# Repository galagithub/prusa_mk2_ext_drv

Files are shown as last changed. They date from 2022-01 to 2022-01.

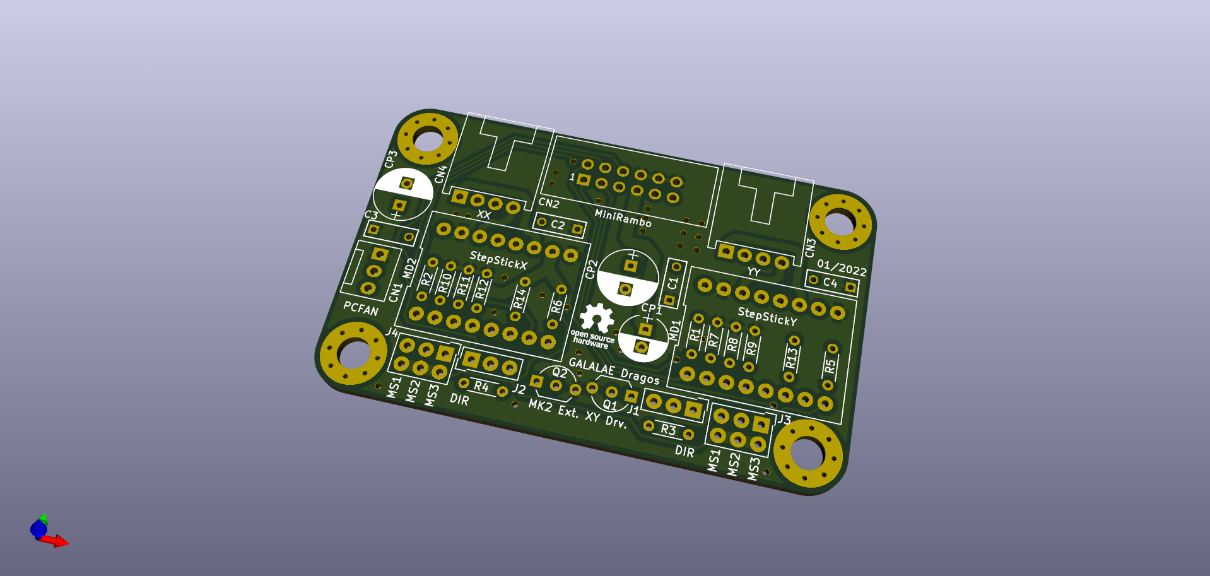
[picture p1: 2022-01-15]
docs/prusa_mk2_ext_drv_v01_2022.png

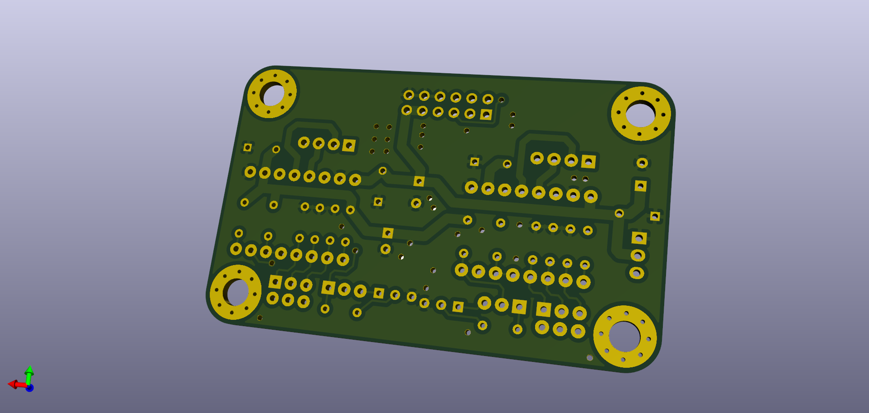
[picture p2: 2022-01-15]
docs/prusa_mk2_ext_drv_v01_2022_back.png

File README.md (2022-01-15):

This is a PCB made to replace the X and Y drivers used the Prusa MK2(S) or MK2.5(S) series of 3D printers.

A closed source kit can be purchased on the web, but the cost is prohibitive for large quantities.
So I have scoured the web for info about the controller used in the 3D printer, MiniRambo v1.3.
Eventually, I managed to compile the schematics enclosed in this github project.

I have used KiCAD v5.1 to design a PCB similar in dimensions to the closed source kit.
Reason being the availability of ready made 3D enclosure(s), the recommended one can be found here:
https://www.thingiverse.com/thing:2777899

Dimensions for the PCB were "recovered" using MeshLab on the above 3D enclosure(s).

Resources:
1) https://reprap.org/wiki/MiniRambo
2) https://reprap.org/wiki/RAMPS_1.4
3) https://reprap.org/wiki/StepStick
4) https://learn.watterott.com/silentstepstick/pinconfig/tmc2209/
5) https://www.thingiverse.com/thing:2777899
6) https://vmod.wordpress.com/prusa-mk2s-ext-driver-board-v2-3/
7) https://www.kicad.org/

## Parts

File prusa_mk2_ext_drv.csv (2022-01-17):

Id | Designator | Package | Quantity | Designation | Supplier and ref
1 | CN4 | Molex_70553_4P | 1 | Y_MOT
2 | CP1 | CP_Radial_D6.3mm_P2.50mm | 1 | 47u/35V
3 | J1 | JP_2.54mm_3PIN | 1 | DirRevX
4 | MD1 | STEPSTICK | 1 | TMC2209_X
5 | MD2 | STEPSTICK | 1 | TMC2209_Y
6 | Q1,Q2 | TO-92_Inline_Wide | 2 | BC546
7 | R2,R6,R1,R5,R13,R14 | R_Axial_DIN0204_L3.6mm_D1.6mm_P5.08mm_Horizontal | 6 | 10k
8 | R4,R11,R3,R10,R12,R8,R7,R9 | R_Axial_DIN0204_L3.6mm_D1.6mm_P5.08mm_Horizontal | 8 | 100k
9 | REF**,REF**,REF**,REF** | MountingHole_4.3mm_M4_Pad_Via | 4 | MountingHole_4.3mm_M4_Pad_Via
10 | J4 | JP_2.54mm_2x3PIN | 1 | CfgY
11 | J2 | JP_2.54mm_3PIN | 1 | DirRevY
12 | J3 | JP_2.54mm_2x3PIN | 1 | CfgX
13 | CP3,CP2 | CP_Radial_D8.0mm_P3.50mm | 2 | 220u/35V
14 | C2,C4,C1,C3 | C_Rect_L7_W2.5_P5 | 4 | 100n/35V
15 | CN3 | Molex_70553_4P | 1 | X_MOT
16 | CN2 | IDC_Header_Straight_12pins | 1 | MiniRambo
17 | CN1 | Fan_Pin_Header_Straight_1x03 | 1 | FAN

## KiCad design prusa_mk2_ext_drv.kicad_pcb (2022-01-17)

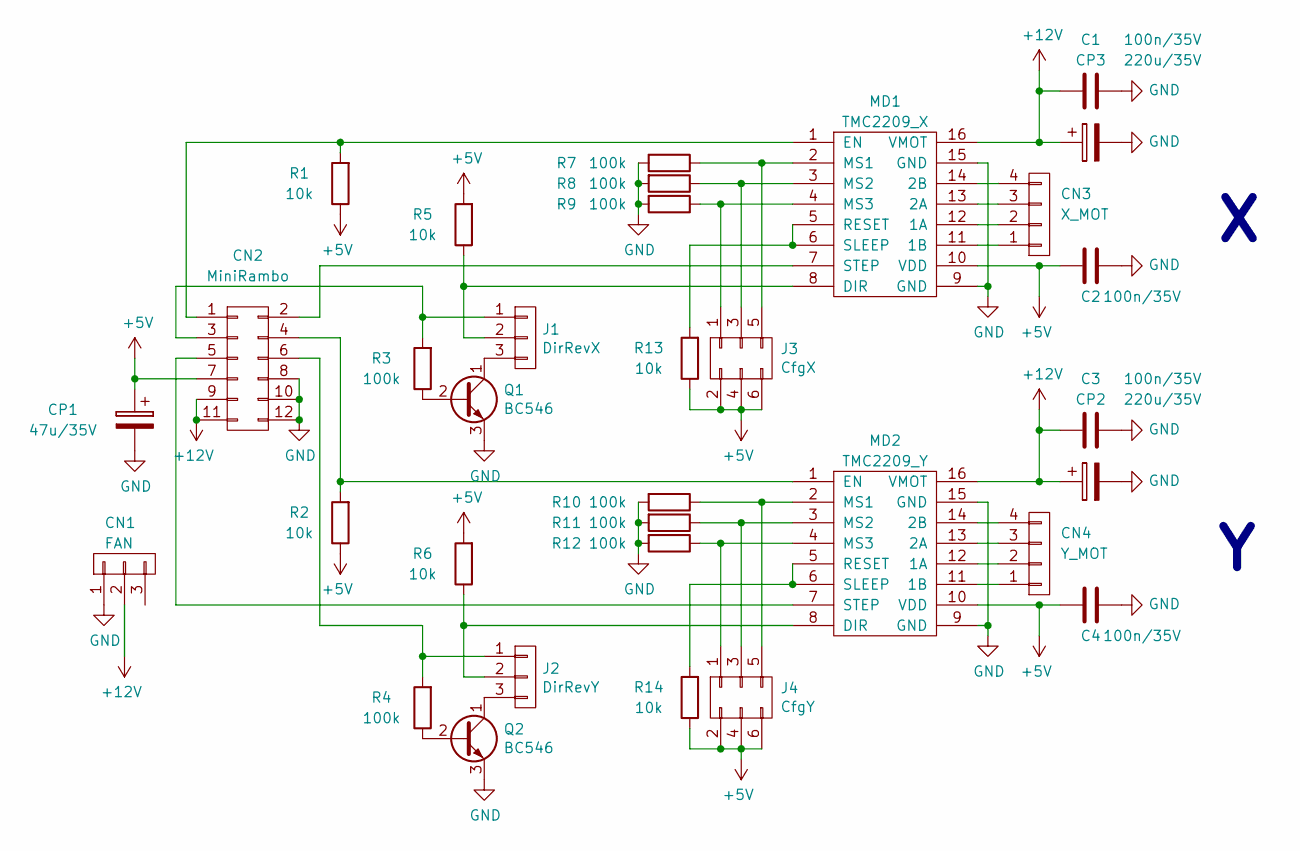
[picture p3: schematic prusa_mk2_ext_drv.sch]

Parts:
C1, C2, C3, C4: 100n/35V; C_Rect_L7_W2.5_P5
CN1: FAN; Fan_Pin_Header_Straight_1x03
CN2: MiniRambo; IDC_Header_Straight_12pins
CN3: X_MOT; Molex_70553_4P
CN4: Y_MOT; Molex_70553_4P
CP1: 47u/35V; CP_Radial_D6.3mm_P2.50mm
CP2, CP3: 220u/35V; CP_Radial_D8.0mm_P3.50mm
J1: DirRevX; JP_2.54mm_3PIN
J2: DirRevY; JP_2.54mm_3PIN
J3: CfgX; JP_2.54mm_2x3PIN
J4: CfgY; JP_2.54mm_2x3PIN
MD1: TMC2209_X; STEPSTICK
MD2: TMC2209_Y; STEPSTICK
Q1, Q2: BC546; TO-92_Inline_Wide
R1, R2, R5, R6, R13, R14: 10k; R_Axial_DIN0204_L3.6mm_D1.6mm_P5.08mm_Horizontal
R3, R4, R7, R8, R9, R10, R11, R12: 100k; R_Axial_DIN0204_L3.6mm_D1.6mm_P5.08mm_Horizontal

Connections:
+5V: C2.2, C4.2, CN2.7, CP1.1, J3.2, J3.4, J3.6, J4.2, J4.4, J4.6, MD1.10 (VDD), MD2.10 (VDD), R1.1, R2.1, R5.2, R6.2, R13.1, R14.1
+12V: C1.2, C3.2, CN1.2, CN2.9, CN2.11, CP2.1, CP3.1, MD1.16 (VMOT), MD2.16 (VMOT)
GND: C1.1, C2.1, C3.1, C4.1, CN1.1, CN2.8, CN2.10, CN2.12, CP1.2, CP2.2, CP3.2, MD1.9 (GND), MD1.15 (GND), MD2.9 (GND), MD2.15 (GND), Q1.3 (E), Q2.3 (E), R7.2, R8.2, R9.2, R10.2, R11.2, R12.2
unnamed: CN2.1, MD1.1 (EN), R1.2
unnamed: CN2.2, MD1.7 (STEP)
unnamed: CN2.3, J1.1, R3.2
unnamed: CN2.4, MD2.1 (EN), R2.2
unnamed: CN2.5, MD2.7 (STEP)
unnamed: CN2.6, J2.1, R4.2
unnamed: CN3.1, MD1.11 (1B)
unnamed: CN3.2, MD1.12 (1A)
unnamed: CN3.3, MD1.13 (2A)
unnamed: CN3.4, MD1.14 (2B)
unnamed: CN4.1, MD2.11 (1B)
unnamed: CN4.2, MD2.12 (1A)
unnamed: CN4.3, MD2.13 (2A)
unnamed: CN4.4, MD2.14 (2B)
unnamed: J1.2, MD1.8 (DIR), R5.1
unnamed: J1.3, Q1.1 (C)
unnamed: J2.2, MD2.8 (DIR), R6.1
unnamed: J2.3, Q2.1 (C)
unnamed: J3.1, MD1.4 (MS3), R9.1
unnamed: J3.3, MD1.3 (MS2), R8.1
unnamed: J3.5, MD1.2 (MS1), R7.1
unnamed: J4.1, MD2.4 (MS3), R12.1
unnamed: J4.3, MD2.3 (MS2), R11.1
unnamed: J4.5, MD2.2 (MS1), R10.1
unnamed: MD1.5 (RESET), MD1.6 (SLEEP), R13.2
unnamed: MD2.5 (RESET), MD2.6 (SLEEP), R14.2
unnamed: Q1.2 (B), R3.1
unnamed: Q2.2 (B), R4.1

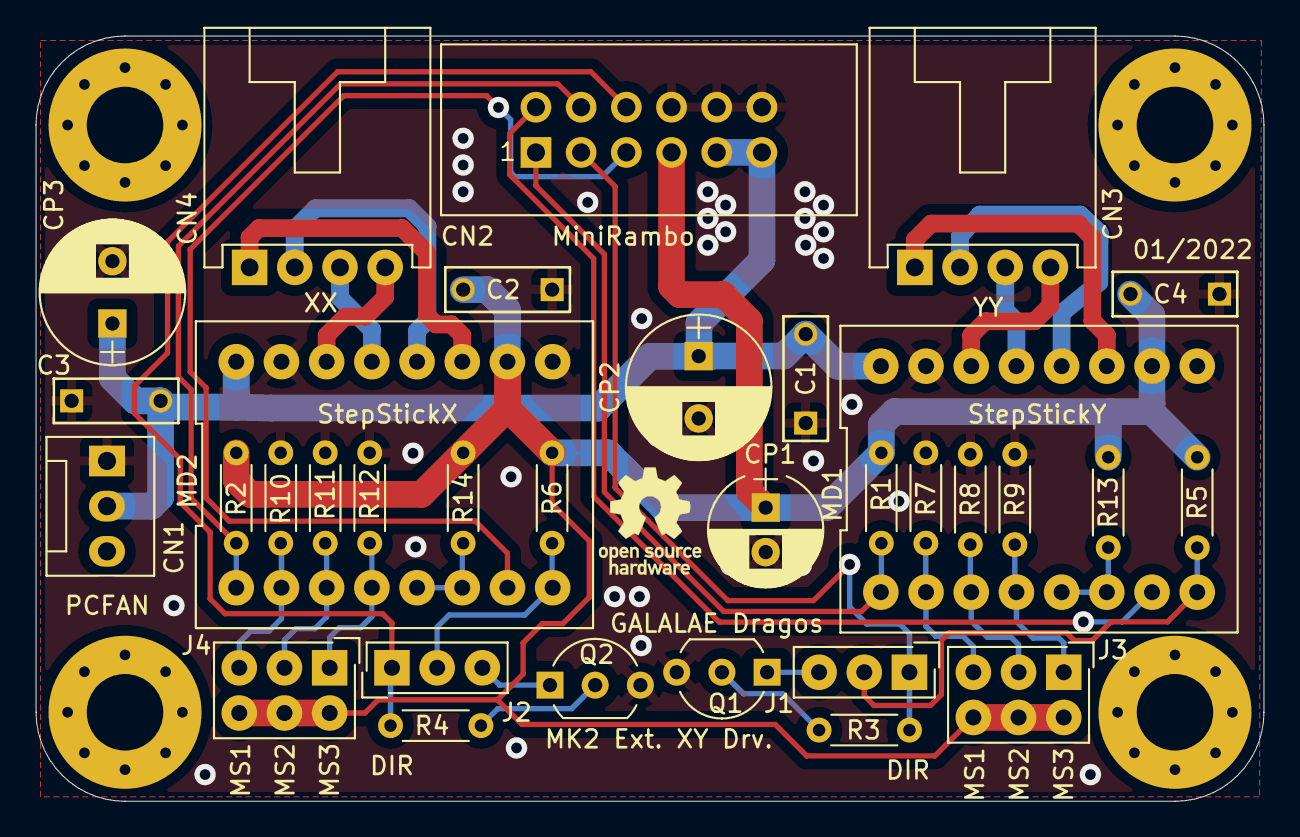
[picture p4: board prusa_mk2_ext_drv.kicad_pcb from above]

Board: 2 copper layers, 69.0 x 43.0 mm, 33 parts (0 on the bottom side), 31 nets.

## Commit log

2022-01-15 Initial PCB ready for release
    [prusa_mk2_ext_drv.kicad_pcb, prusa_mk2_ext_drv.sch]
2022-01-15 Add render and fix shorting via.
    [prusa_mk2_ext_drv.kicad_pcb]
2022-01-17 Initial version was sent to manufacturing, also made cosmetic changes and DRC with the new KiCAD v.6.0
    [prusa_mk2_ext_drv-B_Cu.gbr, prusa_mk2_ext_drv-B_Mask.gbr, prusa_mk2_ext_drv-B_Silkscreen.gbr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]
2022-01-19 Upload PCB backup files
